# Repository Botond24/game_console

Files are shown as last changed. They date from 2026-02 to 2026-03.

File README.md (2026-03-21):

# game_console
name tbd

## Firmware Block Diagram

```mermaid
flowchart TD
    SD[(SD Card\nFAT32)]

    subgraph Core0 ["Core 0 -- Bootloader"]
        Menu["Menu\n- Lists .bin files from SD\n- Selects & launches game"]
        Overlay["Overlay Loop\n- Monitors A+B+UP\n- Kills game, returns to menu"]
        HAL["HAL\n- draw_pixel()\n- read_input()"]
    end

    subgraph Core1 ["Core 1 -- User Game"]
        Game["Game Binary\n- Loaded into RAM @ 0x20010000\n- Owns its own loop\n- Calls HAL only"]
    end

    subgraph Hardware ["Peripherals"]
        OLED["OLED Display\n(mutex-guarded)"]
        BTN[Buttons]
    end

    SD -->|"Read once at launch"| Menu
    Menu -->|"memcpy to 0x20010000\npush addr via FIFO"| Game
    Menu -->|"starts"| Overlay
    Overlay -->|"rp2040.restartCore1()\non A+B+UP"| Game
    Game -->|"calls"| HAL
    HAL -->|"drawPixel()"| OLED
    HAL -->|"reads"| BTN
```

## Folders

- `bootloader/` - Core bootloader firmware for the RP2040 that runs on Core 0. You don't need to touch this unless you want to.
- `game/` - Template game project structure and example game firmware that runs on Core 1. This is the base template for developing new games.
- `pcb/` - Hardware design files including the KiCad PCB schematic, layout, footprints library, and production files (BOM, positions, netlist).
- `test-games/` - Test games and development utilities for validation and demonstration purposes.

## Notes 

- Everything is incredibly rudimentary and you shouldn't expect us to respond to issues. We welcome contributions though, so if you want to add features or fix bugs, fork the repo and send a PR.
- Add your game to the [discussions tab](https://github.com/CircuitReeRUG/game_console/discussions/4)! We would love to see what you make with this!
- You can tag @frogspyder on the Cover Discord server if you want to chat about anything related to this project and/or drop by in the [Discord thread](https://discord.com/channels/1073220526585159681/1484931557876826284).

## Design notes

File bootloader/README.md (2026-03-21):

Unfortunately, you'll have to learn a little bit of PlatformIO to be able to program your game console. Fortunately, it's not that hard.

The project is structured in a way that should be familiar to anyone who has done C programming before. The `src` directory contains the source files, while the `include` directory contains the header files. The `lib` directory contains any libraries that the project depends on (you won't need to worry about this, unless you can't add a library using PlatformIO's library manager).

Obviously, `main.cpp` is the entry point of the program. 

## Project Structure

- `src/` — Bootloader firmware (PlatformIO, Arduino framework)
- `game/` — **Game template**: this is what you should edit/copy to make your own game.
- `test-games/` — Example games

## The Bootloader

1. Initializes the OLED display and shows the splash screen
2. Initializes the SD card (must be FAT32 formatted)
3. Initializes the buttons
4. Shows the game menu

From the menu:
- **A** = select a `.bin` game to launch, or enter USB upload mode
- **B** = rescan the SD card
- **A + B + UP** (held briefly) = kill a running game (reboots the console, lol)

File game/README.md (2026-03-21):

## Writing a Game

1. Go into/Copy the `game/` folder
2. Edit `src/main.cpp` — that's your game
3. Build with `pio run`
4. Copy `.pio/build/pico/firmware.bin` to the SD card (rename to `whatverthefuck.bin`)

### Game Entry Point
As you might have already noticed, your game is a separate PlatformIO project compiled to a raw `.bin` with a custom linker script.

```cpp
#include "game.h" // <- the HAL is already declared for u

extern "C" __attribute__((section(".text.game_entry")))
void game_entry(const HAL* hal) {
    while (true) {
        KeyState k = hal->read_input();
        hal->clear_screen();
        hal->draw_pixel(64, 32, 1);
        hal->render();
        hal->delay_ms(16);
    }
}
```

### HAL Reference

```cpp
struct HAL {
    void (*draw_pixel)(int x, int y, uint16_t color); // 0=black, 1=white
    void (*clear_screen)(void); // clear the framebuffer
    void (*render)(void); // push framebuffer to display
    KeyState (*read_input)(void); // read buttons
    void (*delay_ms)(uint32_t ms); // sleep
    int screen_width; // 128
    int screen_height; // 64
};

struct KeyState {
    bool up, down, left, right;
    bool a, b;
};
```

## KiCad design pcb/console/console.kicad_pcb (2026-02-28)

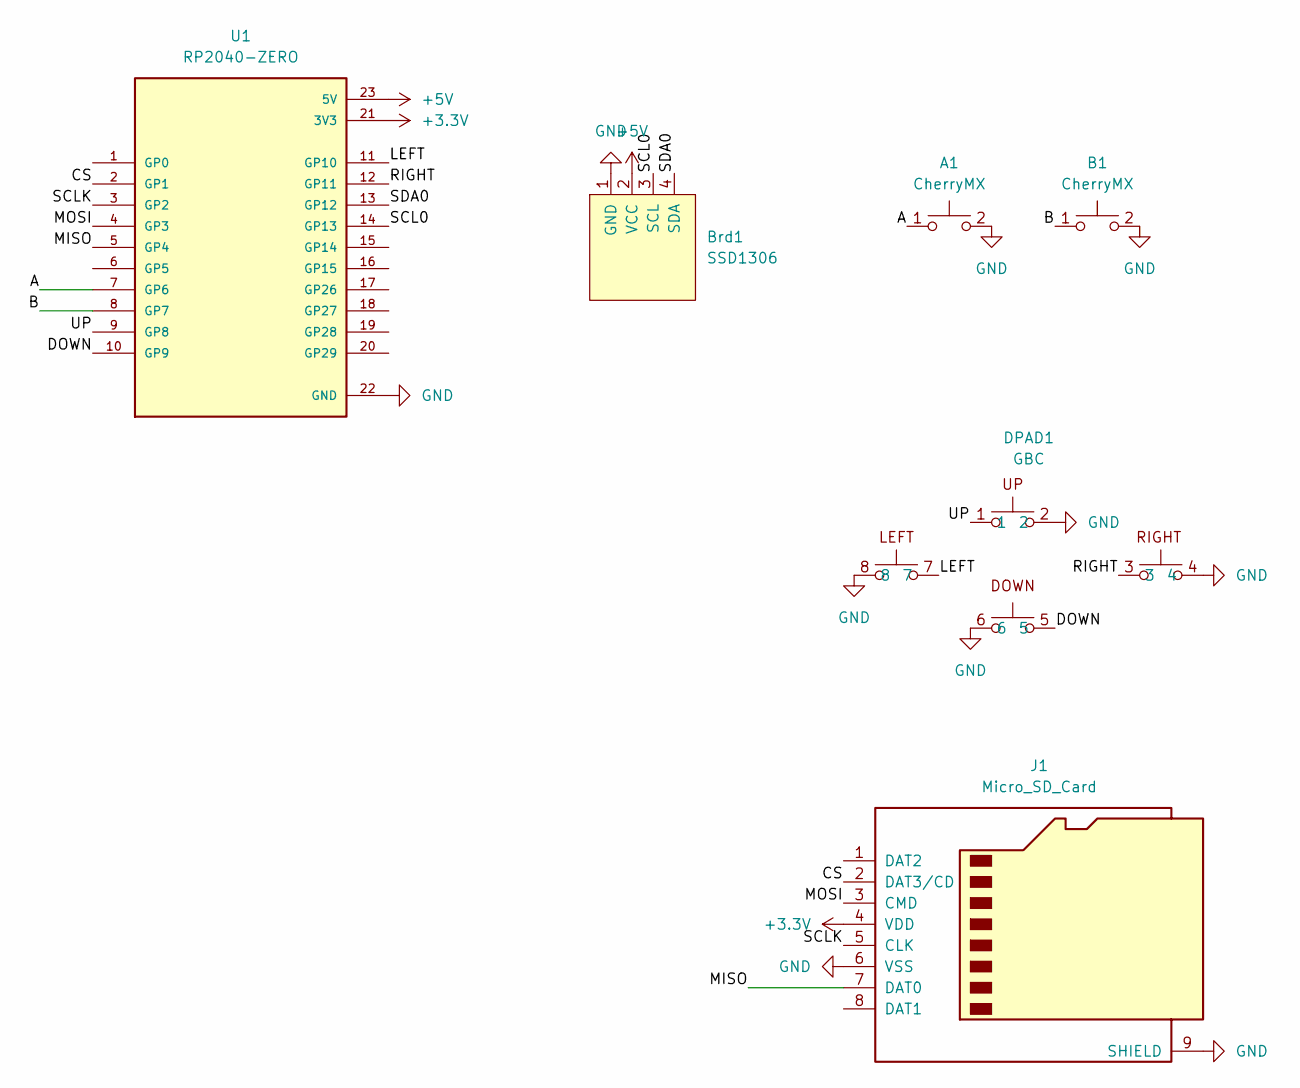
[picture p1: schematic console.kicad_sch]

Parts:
A1: CherryMX; CherryMX_1.00u_KailhSocket
B1: CherryMX; CherryMX_1.00u_KailhSocket
Brd1: SSD1306; 128x64OLED
DPAD1: GBC; GBC DPAD
J1: Micro_SD_Card; microSD_HC_Wuerth_693072010801
U1: RP2040-ZERO; MODULE_RP2040-ZERO; PARTREV NA

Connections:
+3.3V: J1.4 (VDD), U1.21 (3V3)
+5V: Brd1.2 (VCC), U1.23 (5V)
/A: A1.1, U1.7 (GP6)
/B: B1.1, U1.8 (GP7)
/CS: J1.2 (DAT3/CD), U1.2 (GP1)
/DOWN: DPAD1.5, U1.10 (GP9)
/LEFT: DPAD1.7, U1.11 (GP10)
/MISO: J1.7 (DAT0), U1.5 (GP4)
/MOSI: J1.3 (CMD), U1.4 (GP3)
/RIGHT: DPAD1.3, U1.12 (GP11)
/SCL0: Brd1.3 (SCL), U1.14 (GP13)
/SCLK: J1.5 (CLK), U1.3 (GP2)
/SDA0: Brd1.4 (SDA), U1.13 (GP12)
/UP: DPAD1.1, U1.9 (GP8)
GND: A1.2, B1.2, Brd1.1 (GND), DPAD1.2, DPAD1.4, DPAD1.6, DPAD1.8, J1.6 (VSS), J1.9 (SHIELD), U1.22 (GND)

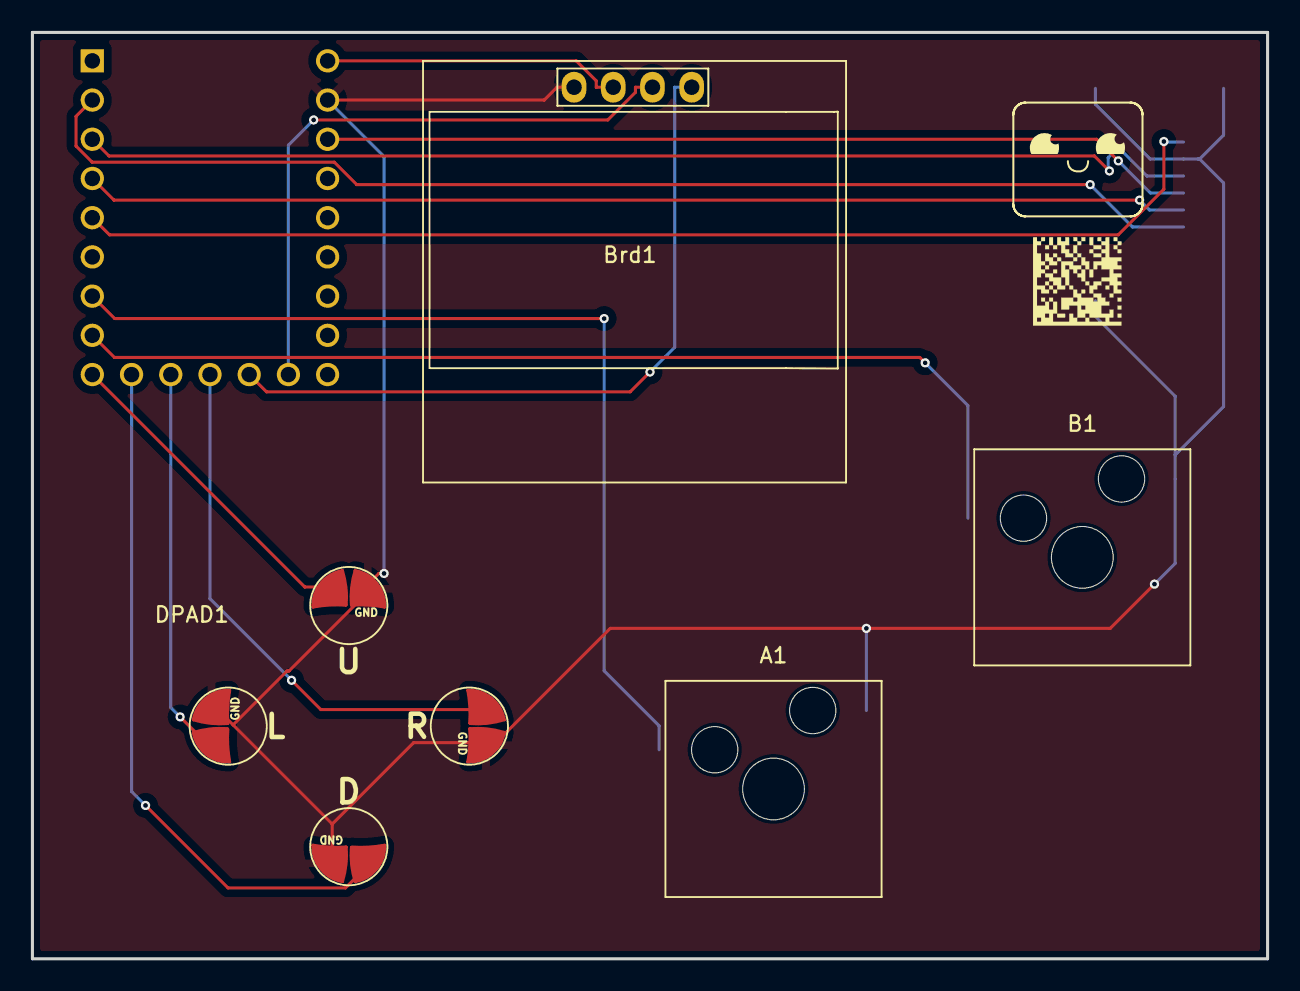
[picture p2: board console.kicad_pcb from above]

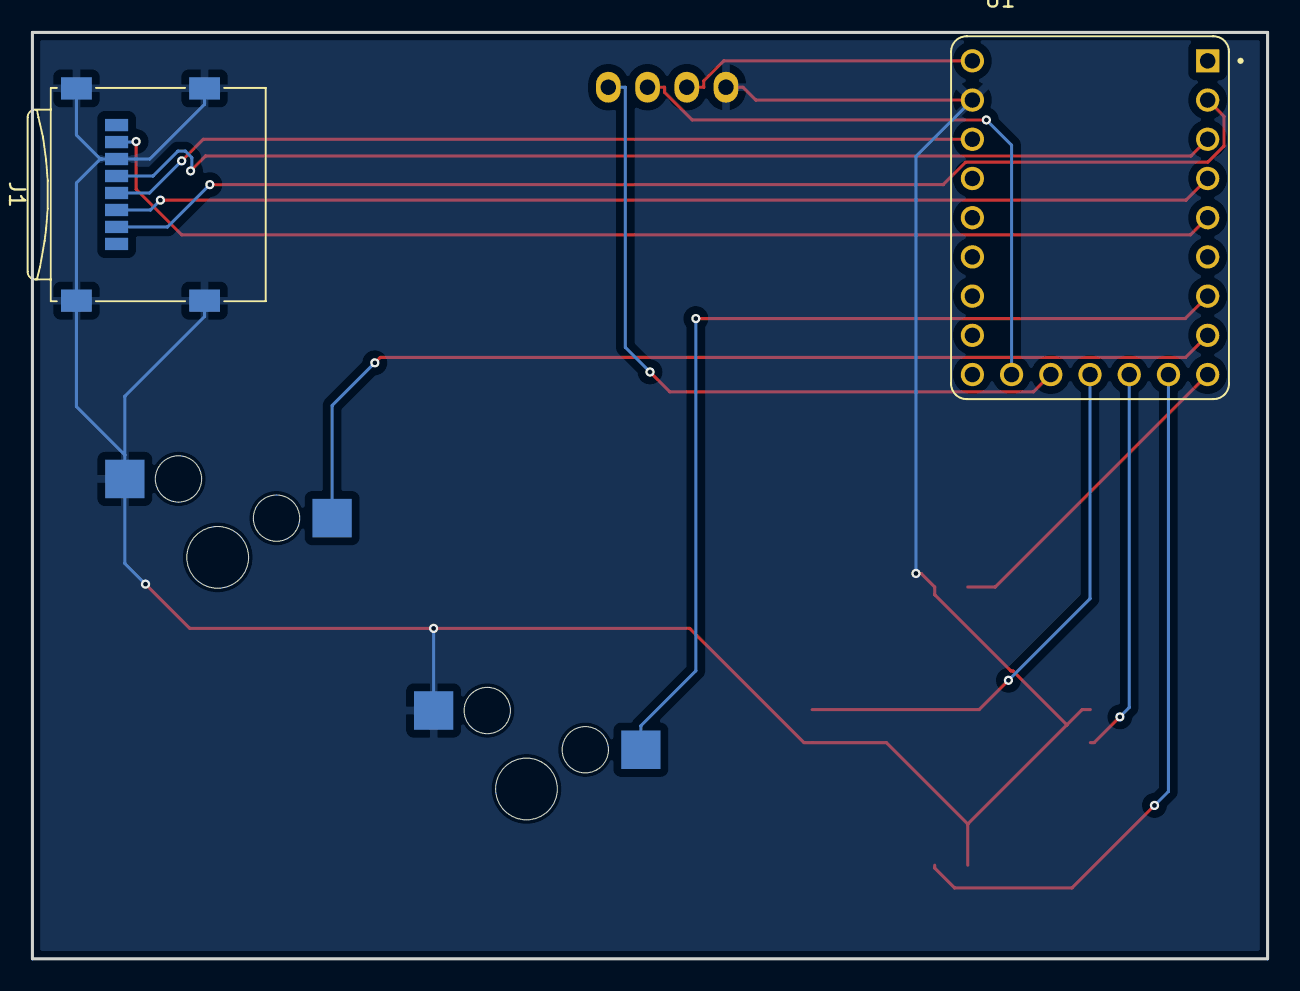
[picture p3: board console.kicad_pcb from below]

Board: 2 copper layers, 80.0 x 60.0 mm, 6 parts (2 on the bottom side), 15 nets.

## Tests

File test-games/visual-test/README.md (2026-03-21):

# Visual Test Game

A minimal game used to verify rendering and input in the bootloader runtime.

Build:
- Run `pio run` in this folder
- Copy .pio/build/pico/firmware.bin to SD root (for example as visual.bin)

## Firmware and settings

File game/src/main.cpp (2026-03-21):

#include "game.h"

// do not touch this function
// it does some funky linker shit
extern "C" __attribute__((section(".text.game_entry")))
void game_entry(const HAL* hal) {
    // example gmae that moves a pixel
    int x = hal->screenWidth / 2;
    int y = hal->screenHeight / 2;

    while (true) {
        KeyState k = hal->readInput();
        if (k.left)  x--;
        if (k.right) x++;
        if (k.up)    y--;
        if (k.down)  y++;

        hal->clearScreen();
        hal->drawPixel(x, y, 1);
        hal->render();
        hal->delayMs(16);
    }
}

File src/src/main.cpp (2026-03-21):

#include "loader/boot.h"
#include <hardware/watchdog.h>

Bootloader bootloader;

void setup() {
    bootloader.init();
}

void loop() {}

void setup1() {}

void loop1() {
    if (!game_running) {
        delay(100);
        return;
    }
    if (digitalRead(PIN_BTN_A) == LOW &&
        digitalRead(PIN_BTN_B) == LOW &&
        digitalRead(PIN_UP) == LOW) {
        watchdog_reboot(0, 0, 10);
    }
    delay(50);
}
